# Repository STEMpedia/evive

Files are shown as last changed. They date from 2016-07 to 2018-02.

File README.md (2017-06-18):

# evive
Contents: evive Design, Test Codes and Hardware Files (Beta version)

evive: transform your ideas to reality.It is an open source embedded platform for all age groups to help them learn, build, debug their robotics, embedded and other projects. With an Arduino Mega at its heart, evive offers a unique menu-based visual interface to make projects, which removes the need to re-program the Arduino repeatedly. evive offers the world of IoT, with power supplies, sensory and actuator support in one small portable kit.

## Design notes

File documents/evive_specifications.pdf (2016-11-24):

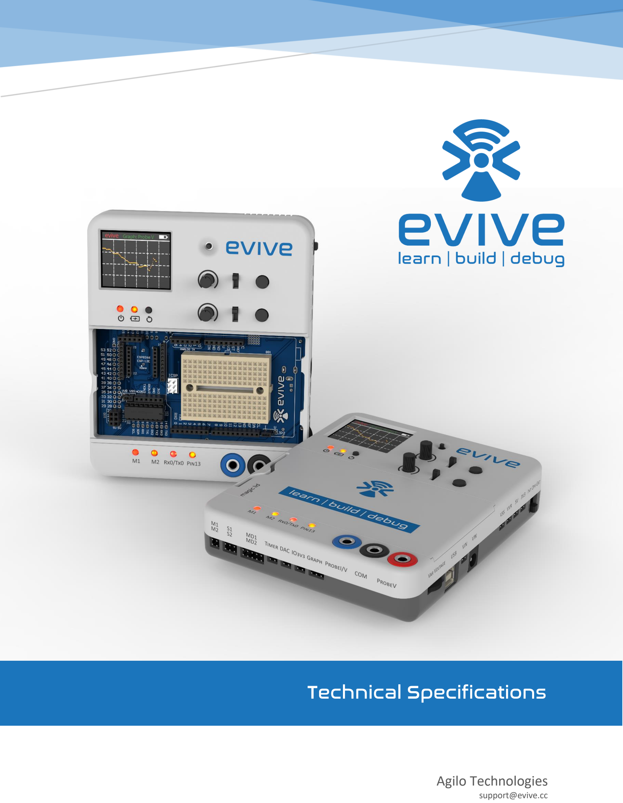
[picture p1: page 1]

## Agilo Technologies

support@evive.cc

# Technical Specifications

# Technical Specifications

Physical | Dimensions: 116mm x 140mm x 32mm Weight: 320g
Microcontroller | Arduino MEGA 2560 R3
Internal Battery | Li-ion battery: 3.7V, 2600mAh, 18650 type Battery Life: Upto 6.5 hours on single charge
External Power Input | USB type B: Upto 1M Baud Rate DC Jack: 5V-30V input with reverse polarity, overcurrent & overvoltage protection Male Headers: Same as DC Jack
Power Output | Stabilized Vin: Stabilized output equal to input voltage Variable Out: 1.25V to Vin-1V, up to 3A Potentiometer controlled 5V Out: Up to 3A 3.3V Out: Up to 800mA
Power Switch | Internal Battery Powered - OFF - Externally Powered
Power Panel | Power LED Charging LED RESET Button
Hardware Interaction | Slide Switches: Two SPST three position slide switches Potentiometers: Two B103 potentiometers Tactile Switches: Two push buttons Joystick: 5-way navigation key
Touch Sensors | 12 Capacitive touch sensor inputs (MPR121QR2)
Display | 1.8" SPI based TFT, 160X128px, 18-bit colour
Buzzer | 2kHz to 10kHz beeps, tones, alerts and melodies

Storage | SD Card Slot: | 2GB to 32GB micro SD card
Communication | Wi-Fi Adapter: ESP-12E (ESP8266) compatible Bluetooth Adapter: HC05 compatible XBee Adapter: S1, S2, PRO etc. compatible
Plug & Play Interface | Two motor channels via inbuilt motor driver M1-M2: 1A per channel with thermal shutdown capability for motors, relays, pneumatics, steppers etc. S1-S2: Two servo motor channels MD1-MD2: Two motor driver channels
Sensing Channels | Probe I/V: I sensing: up to 3A, 3mA accuracy, upto 75kHz V sensing: -5V to +5V, 3mV accuracy, upto 75kHz Probe V: -30V to +30V, 10mV accuracy, up to 75kHz ADCs: Two 24 bit analog to digital converters (ADE7912)
Data Acquisition Channels | Two male headers, each connected to Sensing Channel
Magic Lid | Mini Breadboard: 170 pin solderless Shield Stack Space: Arduino UNO Pinout Compatible 14+14 Digital I/O Pins, 12+3 PWM Output Arduino GPIO: Pins, 6+4 Analog Input Pins, 6 Interrupt, 4 Serial, IIC, SPI
Status Indicators | Rx0-Tx0: Bi-directional LED Pin 13: Unidirectional LED Actuator Directions: Two bi-directional LEDs for M1-M2 etc.
Jumpers | Sensing Selector: Toggle between V or I sensing on Probe I/V Motor Power Toggle between Vin or Vvar for plug & play Selector: devices
DAC | Function Generator: Sine, Square, Sawtooth, Triangular Waves 12 Bit IIC controlled digital to analog converter, 0-5V
Real Time Clock | I 2C interface, Calendar function: YYMMDD, Day, hh:mm:ss, Alarm
I/O 3.3V | Two 5V-3.3V bi-directional digital logic level shifters
Others | Vents: Heat dissipation vents Breadboard Mounting Holes: Two holes to connect breadboards Mounting Holes: Two 4mm holes to mount evive on robots

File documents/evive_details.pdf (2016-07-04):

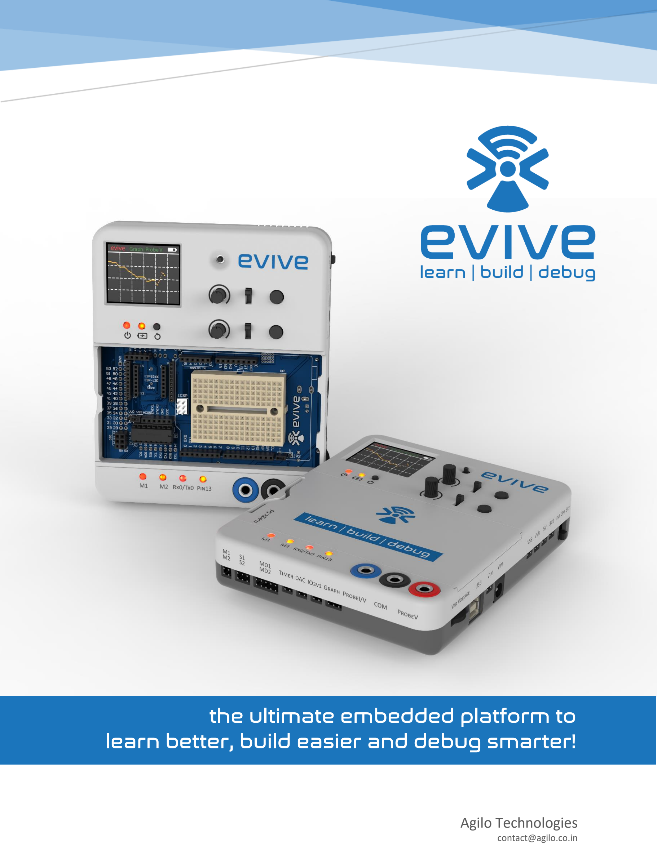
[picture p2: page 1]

### Agilo Technologies

contact@agilo.co.in

## the ultimate embedded platform to learn better, build easier and debug smarter!

1 | P a g e

# Contents

## 1. Brief Introduction

### 1.1 Background & Motivation

Technology - the magical word transforming our world every minute, attracts curiosity and lures everyone to be a part of the revolution. Making stuff is surely fun, but it needs a brave heart to ride along. It takes too much time to develop the relevant skills, too much of hard work to actually realise a project and when it faces a glitch, God bless the maker! It sure requires good amount of patience to debug and make it up and working. But, what if there existed another way, a way to learn quickly and effortlessly. What if you no more have to use extensively complex circuits to build the simplest of prototypes. What if there were alternatives available for effortless analysing and debugging.

Wait no more, bring evive to the team! It will take care of everything from cradle to grave. All you need to do is bring your ideas together. Join the revolution and make the world a better place!

### 1.2 Product Introduction

Introducing evive, an open source embedded platform for novitiates, amateurs and veterans alike to help them learn better, build easier and debug smarter. The name evive derives its meaning from a combination of ‘e’ and ‘vive’. With evive, your electronics can vive!

Compatible with Arduino Mega, evive is equipped with various modes and controls for interacting and learning with hardware. Hardware, which can easily be connected to the plug & play interface and can be controlled using the interaction module. Accurate sensing, plotting and data logging capabilities are provided on this Internet of Things ready platform. It also supports collaborative project development with various other platforms like Raspberry Pi, BeagleBone, Odroid etc. And best of all, it is modular, compact, portable and weighs lesser than an iPad mini.

### 1.3 Product Brief

evive is packed with tons of useful features for everyone. We’ve categorized them into power module, plug & play hardware interface, hardware interaction module, communication module, data acquisition & logging module and building module.

The power module allows a variety of ways to power evive- internal battery, external power source and USB. It also gives several static and a variable power output. Plug & play hardware module allows commonly used hardware to be plugged into the device without complex wiring. Hardware interaction module includes a visual interface and a joystick to choose among various functions. Several switches, potentiometers, buzzers etc. are also provided to interact with your projects better. Communication module allows the board to communicate with external devices via Wi-Fi, Bluetooth or XBee. Data acquisition & logging module consists of accurate voltage & current sensing capabilities. It also allows plotting the data on provided screen and logging it on SD Card with time stamps using a Real Time Clock. Building module allows user to build more, it has a mini breadboard, space for Arduino shields, a provision to connect more breadboards with evive and mounts to attach it your robot.

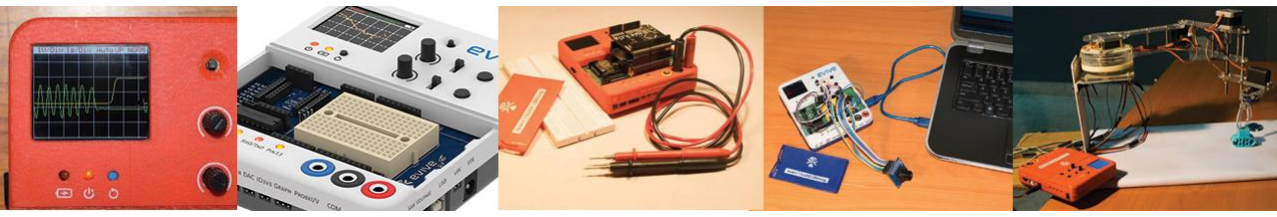
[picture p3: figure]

## 2. Applications

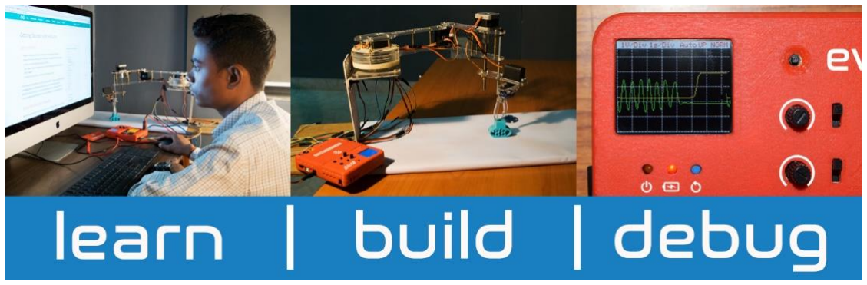
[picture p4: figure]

evive has a wide spectrum of applications. It can be used for learning, teaching, building projects & experimental setups, research, testing, debugging and what not.

For students, evive makes learning easy and fun! It provides a complete interface with sensory inputs, actuator controls, communication capabilities and audio-visual feedback, making it easier for them to learn robotics, programming and embedded systems. The all-in-one platform makes tangled-up wires in your circuits a thing of the past. It also helps reduce the cost involved in sourcing new hardware every time you want to try something.

Hobbyists can say goodbye to clunky and expensive Data Acquisition modules with evive’s highly accurate sensing, logging and graphing capabilities. Ever find yourself obsessed with a small idea that you quickly want to hammer out and test, only to find out you’re missing a necessary component and end up wasting your time bringing things into place? It happened to us many times, but with evive, you’ve got all you need in this self-powered portable unit! The huge array of features in it will certainly reduce the cost involved in procuring expensive shields for exploring new possibilities. It’s all there, in evive!

If you’re an educator or a parent, evive makes teaching easy and effective, giving you loads of teaching modules in one small unit. evive makes your life simple, with the visual and auditory feedback capabilities allowing easy debugging of your students’ projects. It is compatible with graphical programming environments like Scratch, transforming learning into an art.

For researchers and professionals, evive is a bridge between exhaustive equipment like DAQs, oscilloscopes and elementary devices like DMM. Save your time and resources by doing all your beta testing and data logging with evive using its convenient LabVIEW and Python interface. The portability and wireless capability aid in controlling your device and measuring sensor response.

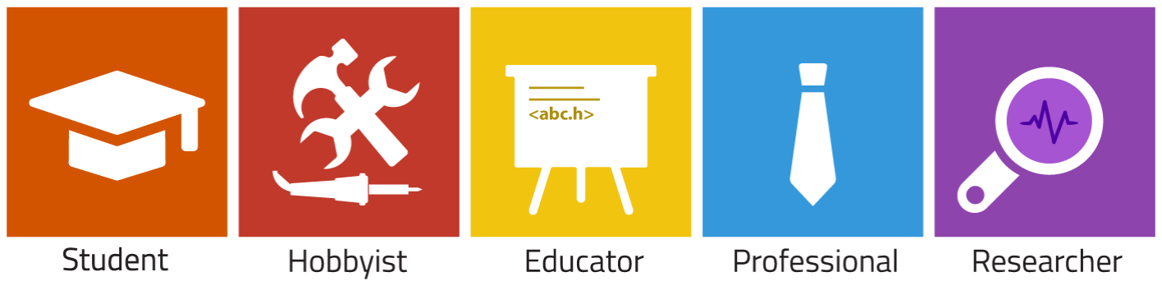
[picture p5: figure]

## 3. Features

### 3.1 Micro Controller

evive has an Arduino MEGA 2560 at its heart. Though several pinouts have been consumed by the device’s internal hardware, Arduino UNO like pinout is provided for connecting shields.

### 3.2 Power Module

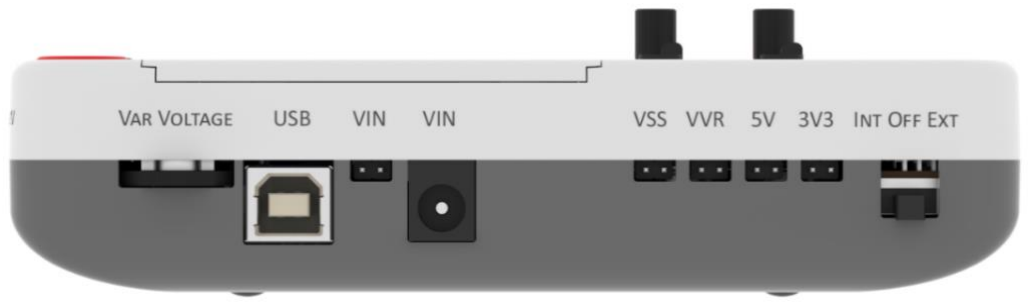
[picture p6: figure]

evive can take 5V - 30V external DC input and is protected against reverse polarity, over voltage & over current. It is also equipped with a 2400 mAh, 3.7V rechargeable internal battery capable of giving up to 1A discharge current. It is protected against low voltage and overcharging via auto-cuts. The device has power supply with stabilized output equal to input voltage, a controllable variable output with up to 3A current limit, a 5V output up to 3A and a 3.3 V output up to 800mA. Power & charging indicators, accurate variable voltage sensing is also provided.

### 3.3 Plug & Play Hardware Interface

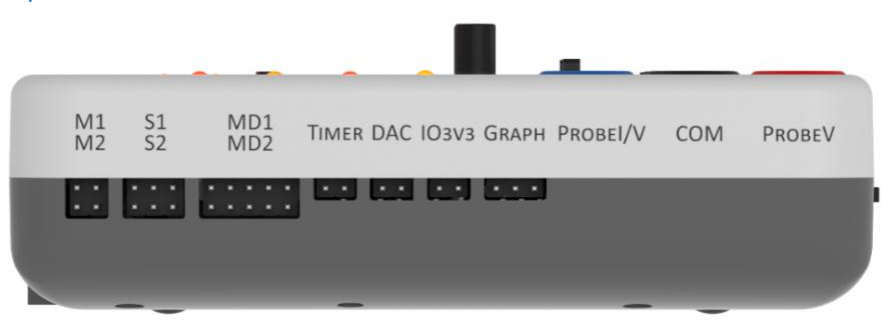
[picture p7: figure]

Allows the user to plug hardware into evive and control it directly from the on-screen user interface. It has two independent DC motor output channels with up to 1A output per channel, protected against overcurrent and overheating. These channels can also be used to plug a stepper motor, pneumatic actuators, solenoid valves, relays etc. Two independent servo motor output terminals and two motor driver connection terminals are also provided along with direction indication LEDs.

### 3.4 Hardware Interaction Module

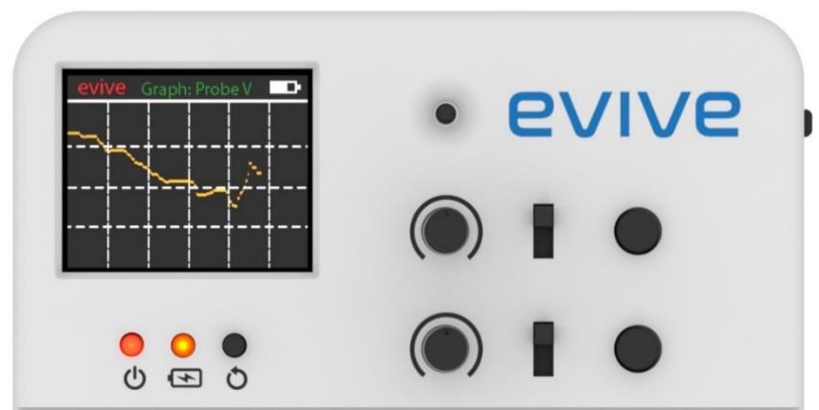
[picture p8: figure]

This module is meant to allow user to interact with evive and all the devices connected with it using on-board switches, potentiometers and the on-screen interface. A 160*128 coloured TFT is provided for displaying all the control modes, graphs, data etc. The on-screen menu can be browsed using the joystick. There are two potentiometers, two 3-position SPDT slide switches, two general purpose tactile switchesto control plug & play devices, scaling on-screen graphs and more. A buzzer is provided for audio and feedback. Being open source, evive also allows the user to use the hardware for any application she wants to.

### 3.5 Communication Module

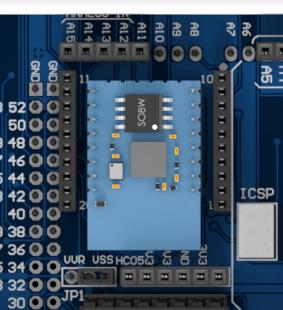
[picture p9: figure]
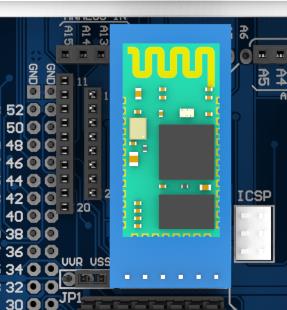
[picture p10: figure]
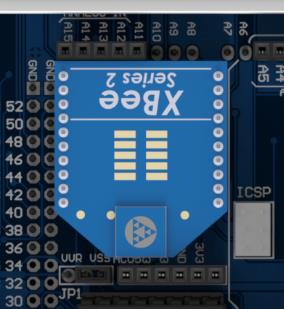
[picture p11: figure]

The communication module allows evive to connect with all your devices for sharing data, plots and other things. It is Internet of Things ready and allows the user to choose from an ESP8266-01 Wi-Fi module, an HC-05 Bluetooth module and good old XBee.

### 3.6 Data Acquisition & Logging Module

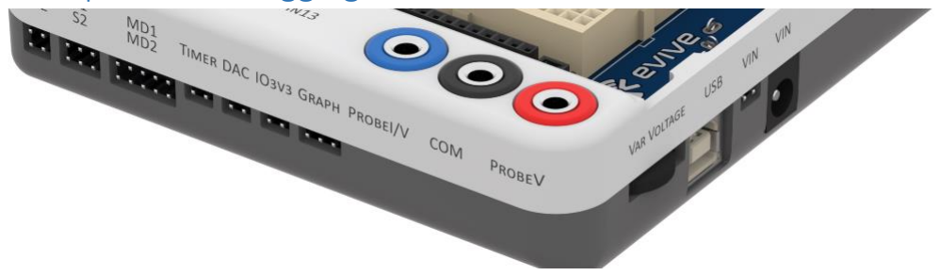
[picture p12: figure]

This module provides evive its sensing, storing and plotting capabilities for advanced users. It can sense voltages in ±30V range with a precision of 10mV and currents up to 3A with a precision of 3mA. The current sensing channel can also be used to sense voltages in ±5V range with a precision of 3mV. Two data acquisition channels are provided, one each for voltage & current sensing. With these, user can read and plot data on the TFT screen or PC or a smartphone. Two 24-bit isolated Analog to Digital converters are behind all the precision. An SD card slot compatible with up to 32GB is also provide to store all your data.

### 3.7 Magic Lid

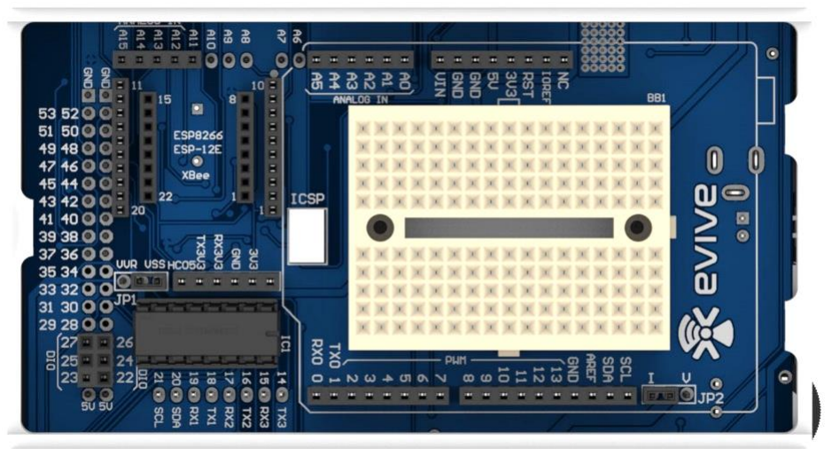
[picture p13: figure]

Present at the centre of evive, allows you to access more features within the evive. It boasts of an Arduino MEGA at heart and a space for mounting UNO/MEGA shields as per need. It has jumpers to toggle between V-I and V-V sensing and to help you choose voltage outputs to plug & play hardware module. It houses the communication module, a mini breadboard to help you connect more sensors, actuators etc. with evive. It also provide access all Arduino MEGA communication pins like IIC, SPI and Serial.

### 3.8 More…

In addition to everything above, evive has more to offer. It has a 16 Bit Timer, a Real Time Clock, a 3.3V I/O channel, four Serial channel, a 12 bit IIC controlled Digital to Analog Converter and a provision to connect more and more breadboards with evive when you’ve complicated circuits to test. Plus, evive comes with an injection moulded plastic case. evive comes with an easy to use LabVIEW interface for all data acquisition, logging, controlling and communication needs. It is also compatible with Arduino IDE, Python, ROS, Scratch, LabVIEW, MATLAB, eclipse and many more. Lots of lessons, tutorials and project examples will also be made available for learners.

## 4. evive’s Story

evive was conceived as a user innovation. The idea of having an all in one debugging kit took form while we were juggling with a student robotics competition. It surely brings immense satisfaction to the maker when they see their robots work. But suddenly, if things don’t go as planned and something goes berserk making your robot mad, it takes days to figure out the problem let alone sort it. Separate testing circuits were required to test different components, and multiple components were tested to figure out which one is faulty. This made the entire process very time consuming and frustrating at times, which was a great setback for the love of making.

So we started working on simplifying the debugging process by developing a testing kit which could test many of the most commonly used hardware. The idea matured and more features were gradually added to it. An aim of integrating everything from learning robotics and embedded systems to building and debugging projects on one platform was set. Our hostel rooms were transformed into laboratories. And after almost nine months of iterations and multiple prototypes, an all-in-one embedded platform for hobbyists, researchers, professionals and learners was introduced on National Technology Day, May 11th 2016.
To our ultimate contentment, evive was born.

## 5. Where to buy

evive will soon be available on Indiegogo, a global crowdfunding platform. You can support us to bring this product to life. Visit bit.ly/evive1 to sign up for the launch.

## 6. Acknowledgements

Agilo Technologies is grateful to Indian Institute of Technology, Kanpur for providing access to various prototyping facilities during development and testing phases. A product is nothing but a fruit of the endless endearing efforts by the people linked to it. In this case they range from various esteemed faculty members and laboratories who supported us and agreed to beta test the product (a special thanks to people at 4i Laboratory, Tinkering Lab and SMSS Lab) to the student Science & Technology community for their valuable feedback on the product.

## 7. Company and the People

Based out of Kanpur, Agilo Technologies was founded in Aug 2015 by a group of robotics enthusiasts at Indian Institute of Technology, Kanpur. The team has been friends for long and they usually spent their time working with robots and embedded systems. All of them have worked for IIT Kanpur’s ROBOCON team. During its initial days, Agilo worked on several robotics & automation projects. One of which was working on mechanical design, control systems and software for a Catalyst Unloading Robot for Reliance Industries Limited. The company also developed an innovative trash compaction device which is currently ‘patent pending’. evive is the first product introduced by Agilo Technologies on Technology Day 2016 held at IIT Kanpur.

### Co-founders

Agilo Technologies was founded by four friends at Indian Institute of Technology Kanpur, one of the most reputed engineering institutes in India.

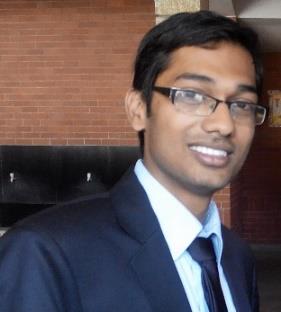
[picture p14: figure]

Abhishek Sharma
talk business to him

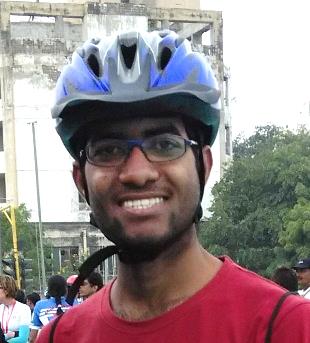
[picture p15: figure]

Dhrupal R Shah
technology guy

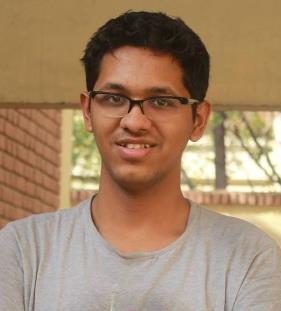
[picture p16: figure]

Akshat Agarwal
builds electronics & code

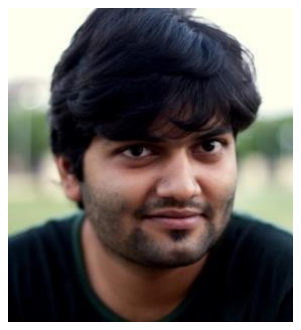
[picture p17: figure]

Pankaj K Verma
the product designer

Abhishek Sharma handles executive, business, finance, legal and marketing aspects of the company. He is enrolled in a BT-MT Dual Degree program in Mechanical Engineering and has experience of working with General Electric as an intern. He has been an avid maker and a part of several projects & competitions. Besides all managerial responsibilities, he contributes to mechanical engineering, design and manufacturing aspects. Outside Agilo, he loves Poker and Volleyball.

Dhrupal R Shah leads the technological development of the company and also handles executive and operational roles. He is enrolled in a BT-MT Dual Degree program in Mechanical Engineering. He has worked with Indian Space Research Organization as an intern and Boeing as an extern. He is an expert at bringing new technologies to the company. Besides technology, he contributes to procurement, fabrication and sales for the company. Besides work, he loves cycling and marathons!

Akshat Agarwal is a junior undergraduate in Electrical Engineering and is working on Artificial Intelligence with Interaction Lab, University of Southern California as an intern. He is responsible for electronics, coding and web development for Agilo. He stays updated with all the technological advances around the globe, loves watching movies, reading and hiking.

Pankaj K Verma is a junior undergraduate in Mechanical Engineering and handles product design and mechanical engineering aspects for the company. He is also responsible for prototyping and manufacturing. Being an explorer, he loves trying new manufacturing techniques, he is team’s 3D Printing lord and loves cricket.

## 8. Contact Information

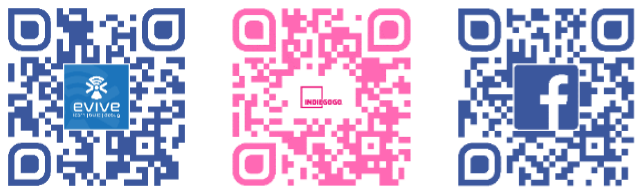
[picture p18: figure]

evive.cc | bit.ly/evive1 | bit.ly/evive2
| support@evive.cc

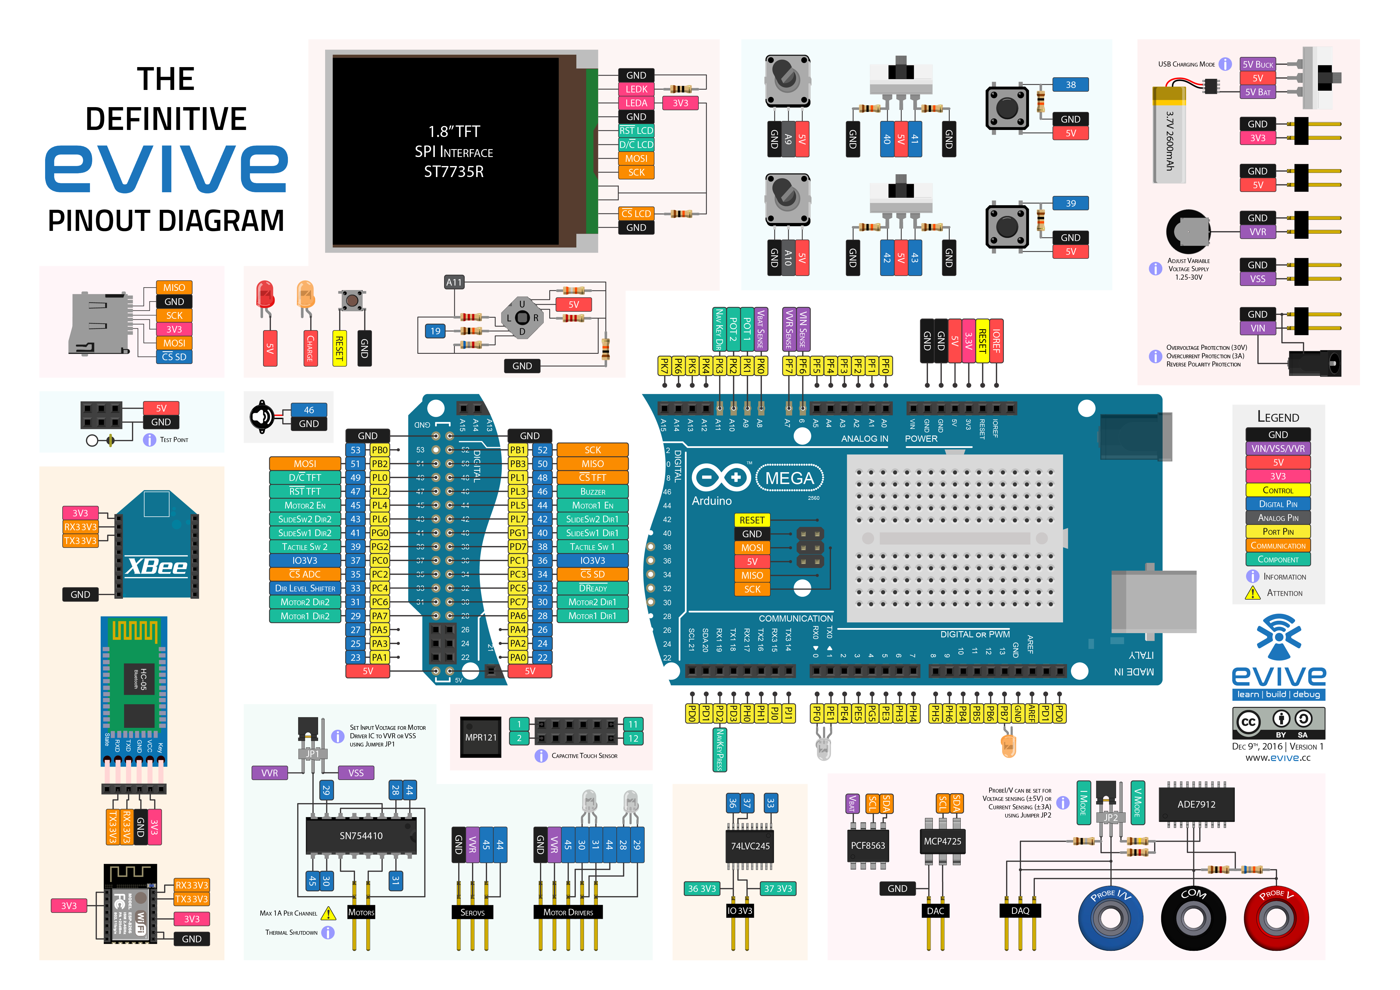
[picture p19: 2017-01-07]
documents/eviveSchematicPinOutDiagram.png

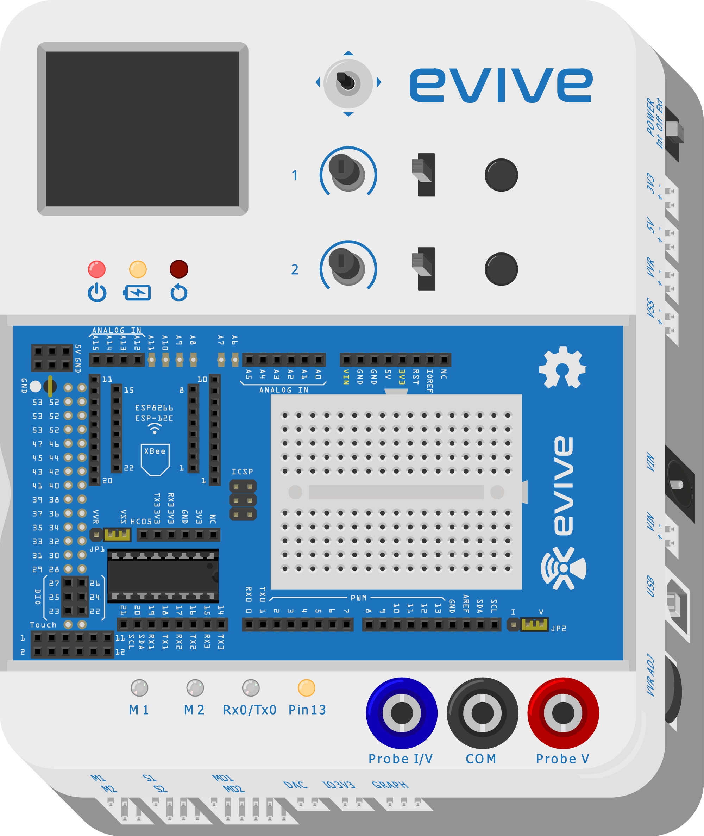
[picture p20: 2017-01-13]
fritzingFiles/evive v1.png

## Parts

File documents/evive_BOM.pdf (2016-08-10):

## evive_v1_BOM

Comment | Description | Designator | Quantity | Pins | Value
BreadBoard | SYB - 170 Pins | BB1 | 1 | 0
BreadBoard | 4*5 100mil | BB2 | 1 | 0
Battery TH 2 Holes | Battery TH 150mil distance Holes | BT1 | 1 | 2
Capacitor 10X10mm | SMD D10mm H10mm 50V | C1 | 1 | 2 | 220uF
Capacitor 6.3X5.4mm | SMD Dia6.3mm, 10V | C2 | 1 | 2 | 220uF
Capacitor 8X10mm | SMD Dia 8mm Height 10mm, 35V | C3 | 1 | 2 | 220uF
C0805 | 35V | C4 | 1 | 2 | 220pF
C0805 | 10V | C5, C6, C13, C15, C19 | 5 | 2 | 10uF
C0805 | 10V | C7, C12, C14, C16, C20, C22, C24 | 7 | 2 | 100nF
C0805 | 16V | C8, C9, C10, C11 | 4 | 2 | 22uF
C0805 | 10V | C17, C18 | 2 | 2 | 22pF
C0805 | 10V | C21, C23 | 2 | 2 | 4u7F
C0805 | 10V | C25, C26 | 2 | 2 | 33nF
SS34 | Schottky Diode | D1, D2, D4 | 3 | 2 | 3A
SS14 | Schottky Diode | D3, D5, D6 | 3 | 2 | 1A
1N4148 | Switching Diode LL34 | D7, D8, D9, D10, D11, D12 | 6 | 2
Ferrite Bead | Ferrite Bead 0805 | FB1, FB2 | 2 | 2 | 150R
SN754410NE | Push-Pull Four Channel Driver With Diode | IC1 | 1 | 16
MCP4725A1T-E/CH | 12-Bit Digital-to-Analog Converter with EEPROM Memory in SOT-23-6, 6-Pin SOT-23, Extended Temperature, Tape and Reel IC2 | | 1 | 6
74LVC245 | OCTAL BUS TRANSCEIVER WITH 3-STATE OUTPUTS IC3 | | 1 | 20
ADE7912ARIZ | ADC with Isolated Power | IC4 | 1 | 20
PCF8563 | RTC | IC5 | 1 | 8
DC Power Jack 2_1mm PTH | DC Power Jack 2.1mm PTH | J1 | 1 | 2
Power | Header 2H | J2 | 1 | 2
VSS | Header 2H | J3 | 1 | 2
VVR | Header 2H | J4 | 1 | 2
V5 | Header 2H | J5 | 1 | 2
3V3 | Header 2H | J6 | 1 | 2
Motor | Header 2X2H | J7 | 1 | 4
Servo | Header 3X2H | J8 | 1 | 6
Motor Driver | Header 5X2H | J9 | 1 | 10
Timer | Header 2H | J10 | 1 | 2
DAC | Header 2H | J11 | 1 | 2
IO3V3 | Header 2H | J12 | 1 | 2
Graph | Header 3H | J13 | 1 | 3
MICROSD | Micro SD, SPI comm | J14 | 1 | 9
Banana Jack | 4mm | J15 | 1 | 1
Banana Jack | 4mm | J16 | 1 | 1
Banana Jack | 4mm | J17 | 1 | 1
LCD | Socket 6 2mm | J19 | 1 | 6
LCD Support | Socket 4 2mm | J20 | 1 | 4
LCD | Header 6 2mm | J21 | 1 | 6
LCD Support | Header 4 2mm | J22 | 1 | 4
Motor Source Jumper | 3Pin 2.54mm | JP1 | 1 | 3
I V | 3Pin 2.54mm | JP2 | 1 | 3
Power Inductor | L38 12X12X7mm 3A | L1, L2 | 2 | 2 | 47uH
Power Inductor | L38 CDRH74R 7X7X4mm 1A | L3 | 1 | 2 | 4u7H
TFT 128X160px | TFT128X160px SPI communication | LCD1 | 1 | 14
LED 3mm | 3mm | LED1, LED2, LED4 | 3 | 2
LED 3mm Bi Clr 3Pin Comm Anode | Common Anode | LED3 | 1 | 3

## evive_v1_BOM

LED 3mm Bi Clr 3Pin Common Cathod | Common Cathod | LED5, LED6 | 2 | 3
Piezo Buzzer | Piezo Buzzer 12mm Dia | LS1 | 1 | 2
Drill 2mm | Hole 2.1mm | MP1, MP2, MP3, MP4, MP5 | 5 | 0
Arduino Mega 2560 R3 | | PCB1 | 1 | 92
ESP8266 ESP-12-E | ESP-12-E Two Female Sockets 8 Ptich: 2mm | PCB2 | 1 | 16
XBEE | XBee Two Female Sockets 10 Ptich: 2mm | PCB3 | 1 | 20
HC05 | Socket 6 | PCB4 | 1 | 6
FDS6675BZ PFET | SOIC-8 | Q1 | 1 | 3
R0805 | | R1, R36 | 2 | 2 | 15k
R0805 | | R3 | 1 | 2 | 3K9
R0805 | | R4 | 1 | 2 | 470 1%
R0805 | | R5 | 1 | 2 | 51k 1%
R0805 | | R6 | 1 | 2 | 10k 1%
R0805 | | R7 | 1 | 2 | 0.3
R0805 | | R8, R12, R13, R14, R15, R16, R33 | 7 | 2 | 2k2
R0805 | | R9, R10, R11 | 3 | 2 | 2k7
R0805 | | R17, R18, R19, R20, R21, R22, R23, R24, R30, R37, R38, R41, R42, R43 | 14 | 2 | 10k
R0805 | | R25 | 1 | 2 | 180k 1%
R0805 | | R26, R29 | 2 | 2 | 1k 1%
R1206 | Shunt Resistor, R010, 10milliohm | R27 | 1 | 2 | 0.01 1%
R0805 | | R28 | 1 | 2 | 68k 1%
R0805 | | R31 | 1 | 2 | 22R
R0805 | | R32 | 1 | 2 | 10R
R0805 | | R34, R39 | 2 | 2 | 6k8
R0805 | | R35 | 1 | 2 | 39k
R0805 | | R40 | 1 | 2 | 1k
R0612 | Network Resistor 0603 X 4 | R44 | 1 | 8 | 10k
PTC 2A RST FUSE | Resettable Fuse | RT1 | 1 | 2 | 2A
Slide Switch SP3T 3Pos | 3 Position PCB RT Mount | S1 | 1 | 3
Tactile Switch 4Pin (2Pin NC) | Tactile Switch 13mm 6X6mm | S2 | 1 | 2
Tactile Switch 4Pin (2Pin NC) | 12mm With Cap | S3, S4 | 2 | 2
Slide Switch SP3T 3Pos | 3 Position PCB Mount | S5, S6 | 2 | 3
5 Way Tactile | 7X7X5mm SMT | S7 | 1 | 6
LM2596 5V | Power Converter 150 KHz 3A Step-Down Voltage Regulator, 5-pin TO-263, Pb-Free U1 | | 1 | 6
LM2596 ADJ | Power Converter 150 KHz 3A Step-Down Voltage Regulator, 5-pin TO-263, Pb-Free U2 | | 1 | 6
1117 | SOT223 | U3 | 1 | 4
TP5410 | TP5410 SOP8-PP Charge+Boost IC Li Cell | U4 | 1 | 8
RPot | Thumbwheel/Gear Potentiometer | VR1 | 1 | 3 | 10K
RPot | RV09 12.5mm Potentiometer | VR2, VR3 | 2 | 3 | 10k
4.096MHz | Crystal, 18.432MHZ, HC49-SMT | X1 | 1 | 2 | 4.096
32.768 kHz | Crystal, 32.768 kHz, DT-38 | X2 | 1 | 2 | 32.768 kHz
Zener Diode | IN4752 | Z1 | 1 | 2 | 33V
Zener Diode | IN4738 | Z2 | 1 | 2 | 12V

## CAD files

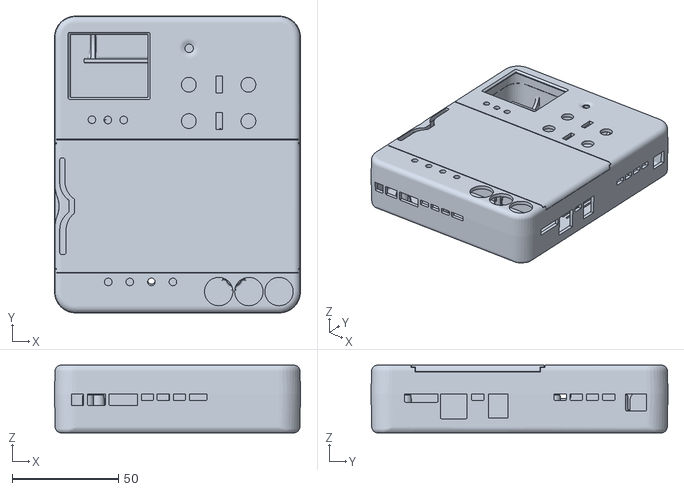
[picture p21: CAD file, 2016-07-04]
hardwareFiles/eviveCasign/eviveAssembly.STL
116.0 x 140.0 x 32.0

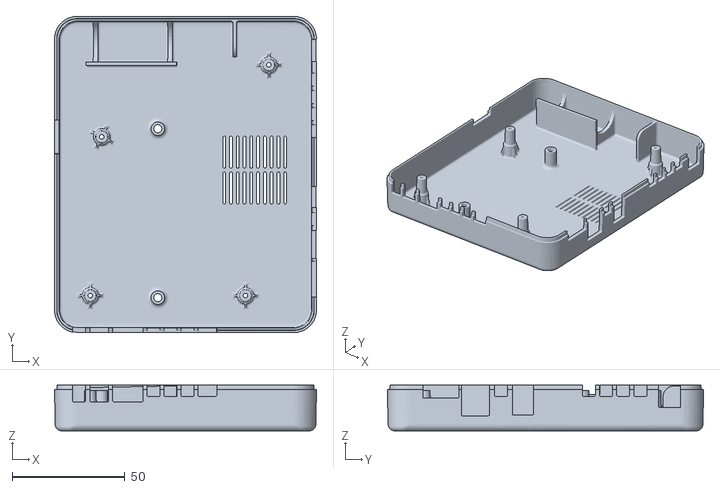
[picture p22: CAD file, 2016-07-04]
hardwareFiles/eviveCasign/eviveBottom.STL
116.0 x 140.0 x 20.3

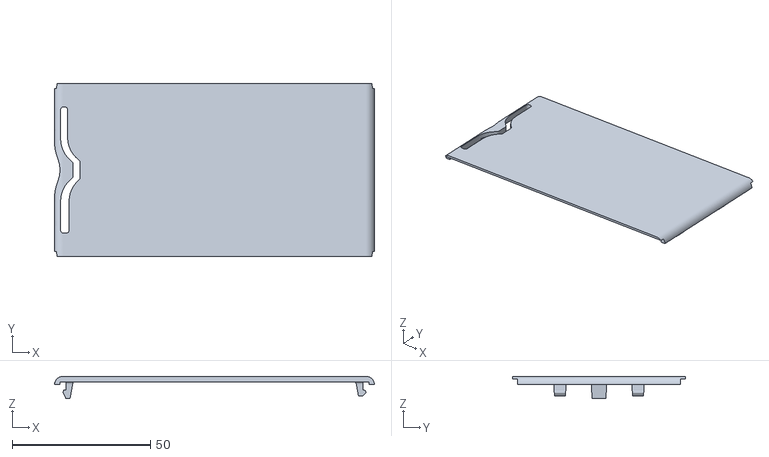
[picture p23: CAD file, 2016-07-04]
hardwareFiles/eviveCasign/eviveLid.STL
115.6 x 62.4 x 8.03

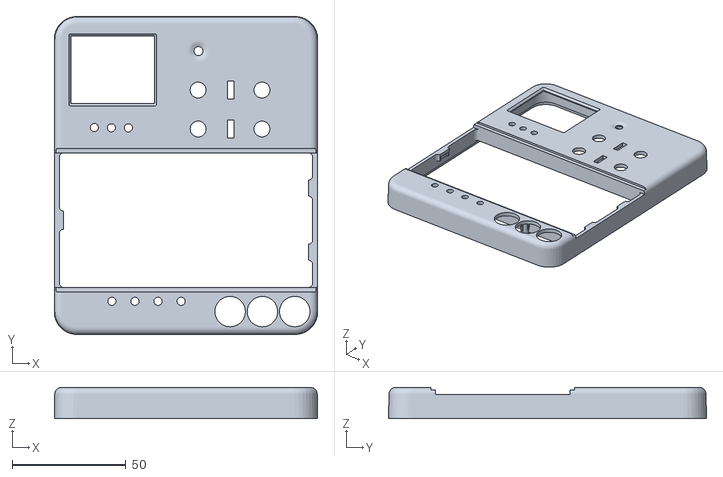
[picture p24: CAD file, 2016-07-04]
hardwareFiles/eviveCasign/eviveTop.STL
116.0 x 140.0 x 13.7

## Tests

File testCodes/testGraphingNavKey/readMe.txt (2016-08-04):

Start=0 or 1
CH0 range (increase/decrease)
CH1 range (increase/decrease)
Sampling Rate
Change trigger modes: TRIG_AUTO, TRIG_NORM, TRIG_SCAN, TRIG_ONE
Send data (to serial)
Save data to SD Card (Yet to be added)
CH0, CH1 offsets (inc/dec) (in discrete values according to VREF)
Trigger level
Trigger rising or falling edge triggered
CH0, CH1 modes (NORM, INV, OFF)

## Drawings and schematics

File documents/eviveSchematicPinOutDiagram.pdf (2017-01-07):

# 1.8” TFT

# ST7735R

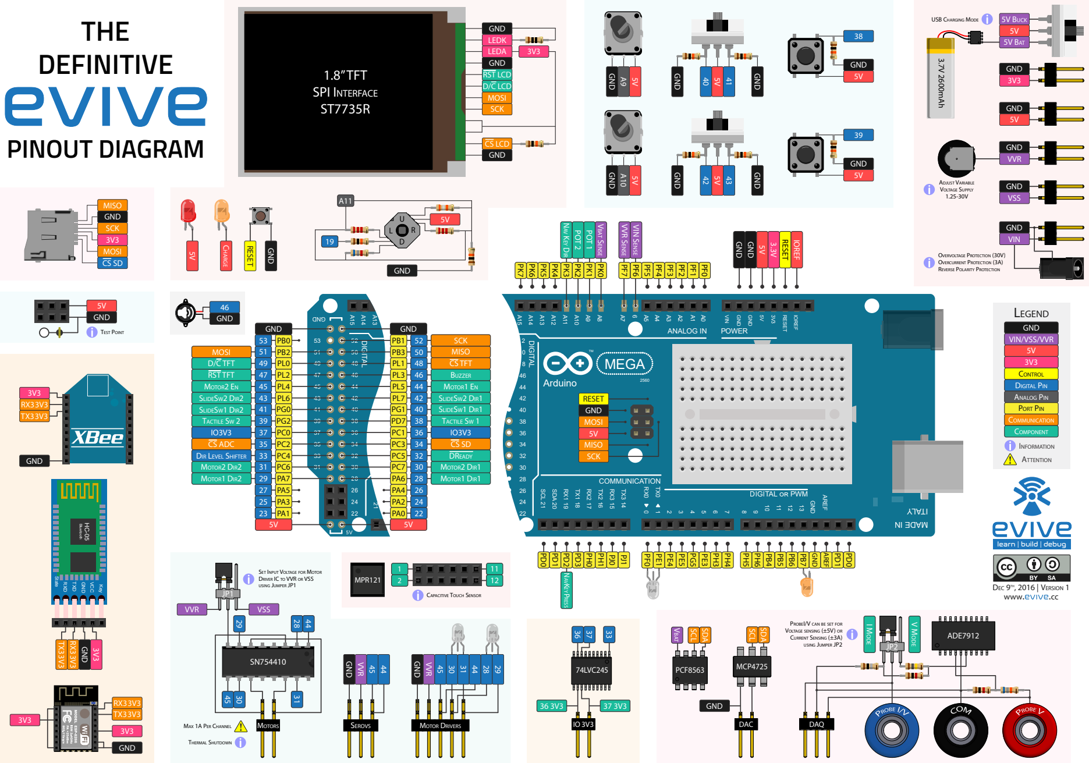
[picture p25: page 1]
A0 ANALOG IN; COMMUNICATION; POWER; AREF; GND; VIN; RESET; SCL 21; SDA 20; DIGITAL; MEGA; IOREF; Arduino; VVR SENSE; VIN SENSE; VBAT SENSE; POT 1; POT 2; SLIDESW1 DIR1; TACTILE SW 1; SLIDESW2 DIR1; MOTOR1 EN; BUZZER; CS TFT; MISO; SCK; MOTOR1 DIR1; MOTOR2 DIR1; DREADY; MOSI; RST TFT; D/C TFT; SLIDESW2 DIR2; MOTOR2 EN; TACTILE SW 2; SLIDESW1 DIR2; CS ADC; MOTOR2 DIR2; DIR LEVEL SHIFTER; MOTOR1 DIR2; MOSI 5V MISO SCK; NAVKEYPRESS; MOSI CS SD; CS LCD; D/C LCD; RST LCD; LEDA; LEDK; SPI INTERFACE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

3.7V 2600mAh USB CHARGING MODE

NAV KEY DIR

OVERVOLTAGE PROTECTION (30V)
OVERCURRENT PROTECTION (3A)
REVERSE POLARITY PROTECTION

DIGITAL OR PWM

learn | build | debug

SET INPUT VOLTAGE FOR MOTOR
DRIVER IC TO VVR OR VSS
USING JUMPER JP1

CAPACITIVE TOUCH SENSOR

PROBEI/V CAN BE SET FOR
VOLTAGE SENSING (±5V) OR
CURRENT SENSING (±3A)
USING JUMPER JP2

MAX 1A PER CHANNEL

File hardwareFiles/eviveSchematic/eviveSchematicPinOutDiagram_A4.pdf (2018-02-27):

# 1.8” TFT

# ST7735R

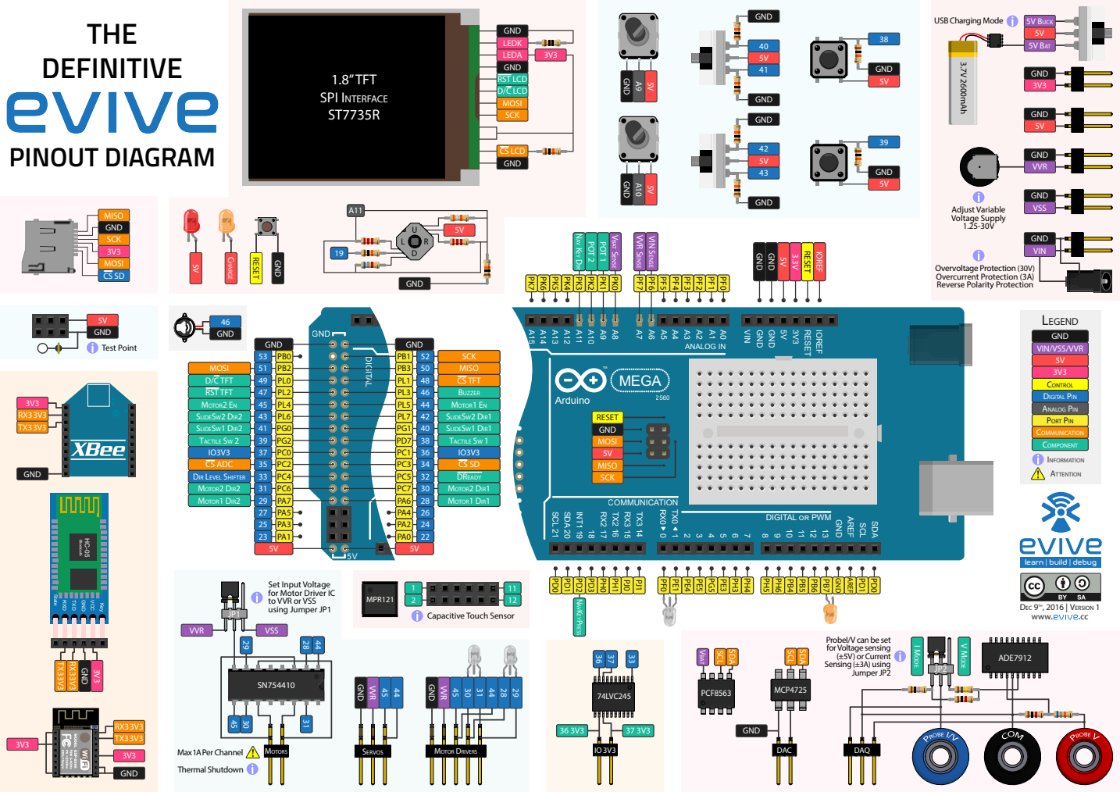
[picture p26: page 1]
A0 ANALOG IN; COMMUNICATION; AREF; GND; VIN; RESET; SCL 21; SDA 20; INT1; MEGA; IOREF; SCL; SDA; Arduino; DIGITAL; VVR SENSE; VIN SENSE; VBAT SENSE; POT 1; POT 2; SLIDESW1 DIR1; TACTILE SW 1; SLIDESW2 DIR1; MOTOR1 EN; BUZZER; CS TFT; MISO; SCK; MOTOR1 DIR1; MOTOR2 DIR1; DREADY; MOSI; RST TFT; D/C TFT; SLIDESW2 DIR2; MOTOR2 EN; TACTILE SW 2; SLIDESW1 DIR2; CS ADC; MOTOR2 DIR2; DIR LEVEL SHIFTER; MOTOR1 DIR2; MOSI 5V MISO SCK; NAVKEYPRESS; MOSI CS SD; CS LCD; D/C LCD; RST LCD; LEDA; LEDK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

USB Charging Mode

NAV KEY DIR

Overvoltage Protection (30V)
Overcurrent Protection (3A)
Reverse Polarity Protection

DIGITAL OR PWM

learn | build | debug

Set Input Voltage
for Motor Driver IC
to VVR or VSS
using Jumper JP1

ProbeI/V can be set
for Voltage sensing
(±5V) orCurrent Sensing (±3A) using
Jumper JP2

Max 1A Per Channel
Thermal Shutdown

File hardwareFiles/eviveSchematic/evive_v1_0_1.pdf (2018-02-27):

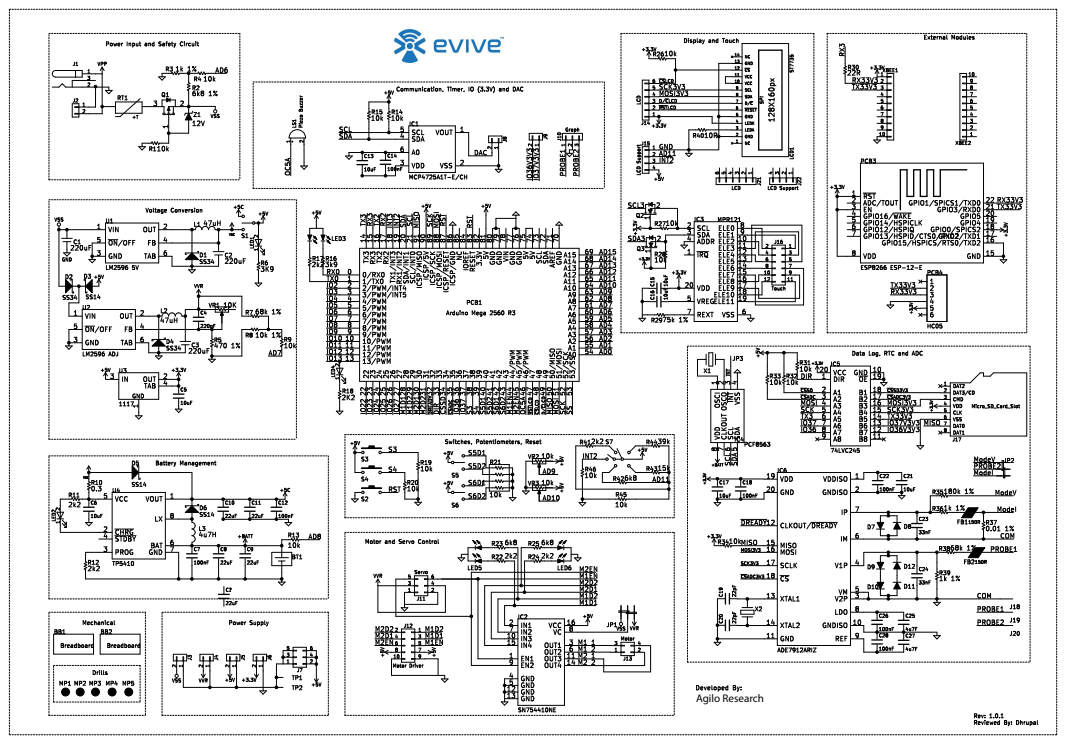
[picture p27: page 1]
Agilo Research

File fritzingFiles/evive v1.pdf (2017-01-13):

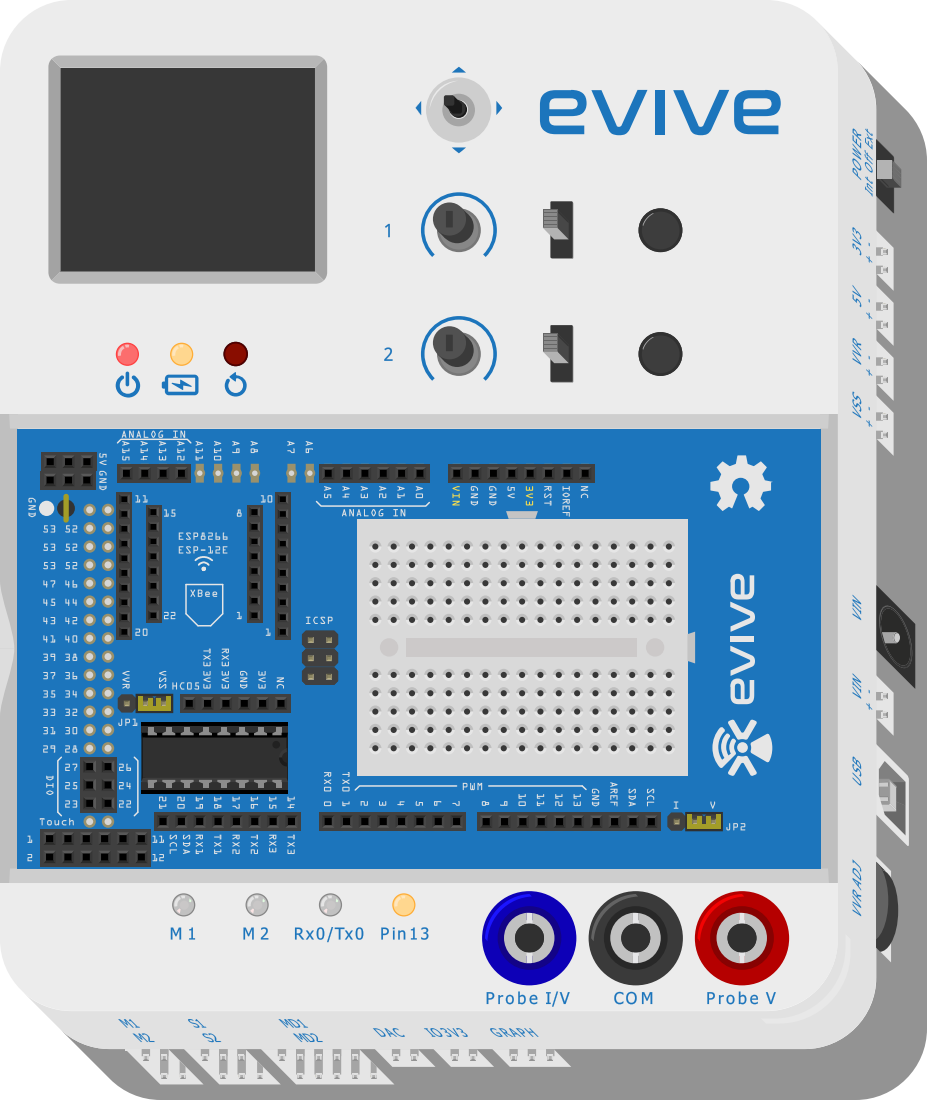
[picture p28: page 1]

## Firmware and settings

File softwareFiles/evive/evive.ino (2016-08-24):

/*
 * This firmware is developed for evive [http://evive.cc].
 * This is licensed under Creative Commons 4.0
 * Written by Dhrupal R Shah and Akshat Agarwal for Agilo Technology.
 * Last update: 2016, Aug 20
 * 
 * NOTE: Works with Arduino IDE 1.6.6 or later [https://www.arduino.cc/en/Main/Software]
 */
 #include "evive.h"

void setup(){
  Serial.begin(BAUDRATE);
  Serial.println("In the setup loop now");
  lcd_init();

  setPinModeDefault();
  Serial.println("setup ends");
}

void loop(){
  lcd_update();
  action();
}

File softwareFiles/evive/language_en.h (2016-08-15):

/****
	*English
	*
****/
#ifndef LANGUAGE_EN_H
#define LANGUAGE_EN_H

/*
*
*GENERAL SECTION
*
*/
#ifndef MSG_PIN_HIGH
	#define MSG_PIN_HIGH						"High"
#endif
#ifndef MSG_PIN_LOW
	#define MSG_PIN_LOW							"Low"
#endif
#ifndef MSG_ON
	#define MSG_ON									"On"
#endif
#ifndef MSG_OFF
	#define MSG_OFF									"Off"
#endif


/*
*HOME SECTION
*
*/
#ifndef WELCOME_MSG
	#define WELCOME_MSG							"Hello"
#endif
#ifndef MSG_HOME_MENU
	#define MSG_HOME_MENU						"evive Home"
#endif
#ifndef MSG_CONTROL	
	#define MSG_CONTROL 						"Control"
#endif
#ifndef MSG_SENSING
	#define MSG_SENSING							"Sensing"
#endif
#ifndef MSG_OSCILLOSCOPE
	#define MSG_OSCILLOSCOPE				"Mini Oscilloscope"
#endif
#ifndef MSG_LOG
	#define MSG_LOG									"Data Log"
#endif
#ifndef MSG_PIN_STATE
	#define MSG_PIN_STATE							"Pin States"
#endif
#ifndef MSG_DAC
	#define MSG_DAC									"Beta Function Generator"
#endif
#ifndef MSG_TIMER
	#define MSG_TIMER								"Timer"
#endif
#ifndef MSG_IO3V3
	#define MSG_IO3V3								"Input-Output (3.3V)"
#endif
#ifndef MSG_OTHER
	#define MSG_OTHER								"Others"
#endif
#ifndef MSG_USER_DEF
	#define MSG_USER_DEF							"User Defined Functions"
#endif
#ifndef MSG_REMOVE_FUNCTION
	#define MSG_REMOVE_FUNCTION				"Remove Function"
#endif

/*
*CONTROL SECTION
*/
#ifndef MSG_CONTROL_MOTOR
	#define MSG_CONTROL_MOTOR						"Motors"
#endif
#ifndef MSG_CONTROL_SERVO
	#define MSG_CONTROL_SERVO						"Servos"
#endif
#ifndef MSG_CONTROL_STEPPER_MOTOR
	#define MSG_CONTROL_STEPPER_MOTOR				"Stepper Motors"
#endif
#ifndef MSG_CONTROL_SLIDESW
	#define MSG_CONTROL_SLIDESW						"Slide Switches"
#endif
#ifndef MSG_CONTROL_TACTILESW
	#define MSG_CONTROL_TACTILESW					"Tactile Switches"
#endif
#ifndef MSG_CONTROL_POT
	#define MSG_CONTROL_POT							"Potentiometers"
#endif
#ifndef MSG_CONTROL_MOTOR_DIR1
	#define MSG_CONTROL_MOTOR_DIR1					"Direction 1"
#endif
#ifndef MSG_CONTROL_MOTOR_DIR2
	#define MSG_CONTROL_MOTOR_DIR2					"Direction 2"
#endif
#ifndef MSG_CONTROL_MOTOR_FORWARD
	#define MSG_CONTROL_MOTOR_FORWARD				"Forward"
#endif
#ifndef MSG_CONTROL_MOTOR_BACKWARD
	#define MSG_CONTROL_MOTOR_BACKWARD				"Backward"
#endif
#ifndef MSG_CONTROL_MOTOR_LOCK
	#define MSG_CONTROL_MOTOR_LOCK					"Locked"
#endif
#ifndef MSG_CONTROL_MOTOR_STOP
	#define MSG_CONTROL_MOTOR_STOP					"Stopped"
#endif
#ifndef MSG_CONTROL_MOTOR_FREE
	#define MSG_CONTROL_MOTOR_FREE					"Free"
#endif
#ifndef MSG_CONTROL_MOTOR_ROTATE
	#define MSG_CONTROL_MOTOR_ROTATE				"Rotating"
#endif
#ifndef MSG_CONTROL_MOTOR_PWM
	#define MSG_CONTROL_MOTOR_PWM					"PWM"
#endif
#ifndef MSG_CONTROL_MOTOR_SPEED
	#define MSG_CONTROL_MOTOR_SPEED					"Speed"
#endif
#ifndef MSG_CONTROL_SERVO_ANGLE
	#define MSG_CONTROL_MOTOR_ANGLE					"Angle"
#endif
#ifndef MSG_CONTROL_SERVO_SPEED
	#define MSG_CONTROL_SERVO_SPEED					"Speed"
#endif
#ifndef MSG_CONTROL_SLIDESW1
	#define MSG_SLIDESW1							"SlideSW 1"
#endif
#ifndef MSG_CONTROL_SLIDESW2
	#define MSG_SLIDESW2							"SlideSW 2"
#endif
#ifndef MSG_CONTROL_MOTOR1
	#define MSG_CONTROL_MOTOR1						"Motor 1"
#endif
#ifndef MSG_CONTROL_MOTOR2
	#define MSG_CONTROL_MOTOR2						"Motor 2"
#endif
#ifndef MSG_CONTROL_MOTOR12
	#define MSG_CONTROL_MOTOR12						"Motor 1 & 2"
#endif
#ifndef MSG_CONTROL_SERVO1
	#define MSG_CONTROL_SERVO1						"Servo 1"
#endif
#ifndef MSG_CONTROL_SERVO2
	#define MSG_CONTROL_SERVO2						"Servo 2"
#endif
#ifndef MSG_CONTROL_SERVO12
	#define MSG_CONTROL_SERVO12						"Servo 1 & 2"
#endif
#ifndef MSG_CONTROL_TACTILESW1
	#define MSG_CONTROL_TACTILESW1					"TactileSW 1"
#endif
#ifndef MSG_CONTROL_TACTILESW2
	#define MSG_CONTROL_TACTILESW2					"TactileSW 2"
#endif

/*
*SENSING
*/
#ifndef MSG_SENSING_PROBE_V
	#define MSG_SENSING_PROBE_V						"ProbeV (+-30V)"
#endif
#ifndef MSG_SENSING_PROBE_I/V_I
	#define MSG_SENSING_PROBE_I/V_I					"ProbeI/V (+-5V)"
#endif
#ifndef MSG_SENSING_PROBE_I/V_V
	#define MSG_SENSING_PROBE_I/V_V					"ProbeI/V (+-3A)"
#endif
#ifndef MSG_SENSING_PROBE_VV
	#define MSG_SENSING_PROBE_VV					"ProbeV (30V) & I/V (5V)"
#endif
#ifndef MSG_SENSING_PROBE_VI
	#define MSG_SENSING_PROBE_VI					"ProbeV (30V) & I/V (3A)"
#endif

/*
*DAC
*/
#ifndef MSG_ANALOG_OUT
	#define MSG_ANALOG_OUT							"Analog Output"
#endif
#ifndef MSG_SINE
	#define MSG_SINE										"Sine Wave"
#endif
#ifndef MSG_SQUARE
	#define MSG_SQUARE									"Square Wave"
#endif
#ifndef MSG_TRIANGULAR
	#define MSG_TRIANGULAR							"Triangular Wave"
#endif
#ifndef MSG_SAWTOOTH_UP
	#define MSG_SAWTOOTH_UP							"Sawtooth Wave (Up)"
#endif
#ifndef MSG_SAWTOOTH_DOWN
	#define MSG_SAWTOOTH_DOWN						"Sawtooth Wave (Down)"
#endif
/*
*ERRORS SECTION
*
*/
#ifndef MSG_ERROR_BATTERY_LOW
	#define MSG_ERROR_BATTERY_LOW					"Battery low. Please charge"
#endif

#endif

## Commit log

2016-07-04 Added evive core files
    [eviveAssembly.STL, eviveBottom.STL, eviveLid.STL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]
2016-07-06 Add evive software [under development]
    This is very primitive software.
    (Only Motor, Servo, Oscilloscope it working)
    [configuration.h]
2016-07-07 added test codes
    [Primitive Version]
    [differentConfigs.txt]
2016-07-09 shifted testcodes
    [differentConfigs.txt]
2016-08-02 Update evive sketches
    Included Functions:
    Control ( motors and servos)
    Sensing (V and I) (Offset depends on device)
    Mini Oscilloscope
    Beta Function Generator
    User Defined Functions
    [configuration.h]
2016-08-04 Added test functions of menu
    [configuration.h]
2018-02-27 Update 1_0_1 hardware
    Misprint in Battery boost circuit.
